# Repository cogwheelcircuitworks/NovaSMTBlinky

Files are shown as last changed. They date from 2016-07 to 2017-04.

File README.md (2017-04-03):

# NovaSMTBlinky

ATtiny-based, Surface-mount, 5x7 LED dot-matrix display board used in classes

More description over on https://hackaday.io/project/7788-nova-smt-blinky 

It has also been known to be for sale on Tindie: https://www.tindie.com/products/bcoggs/nova-smt-blinky--hackable-5x7-dot-matrix-/

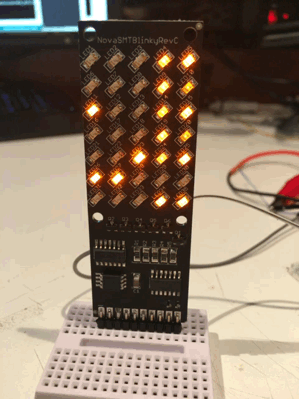
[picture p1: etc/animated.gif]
 

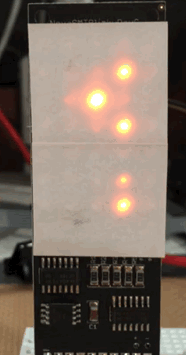
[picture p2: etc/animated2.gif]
 

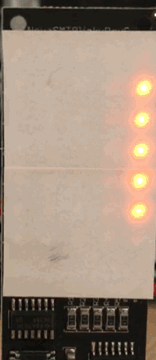
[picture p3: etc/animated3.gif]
 

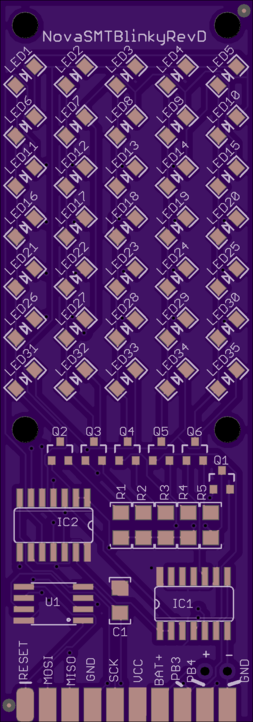
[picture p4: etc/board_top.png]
  

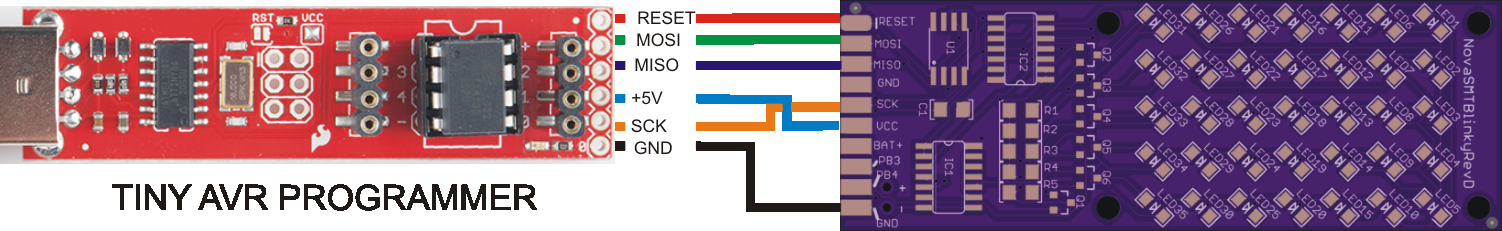
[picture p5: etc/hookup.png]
  

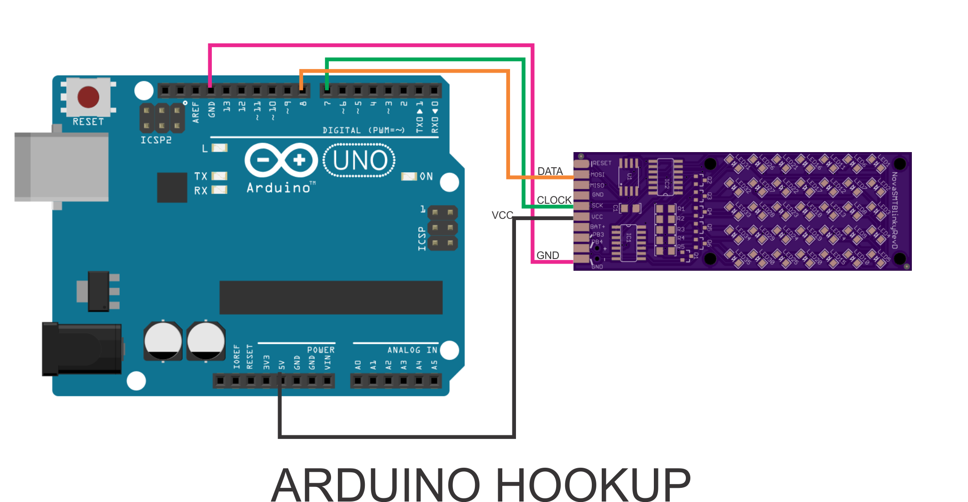
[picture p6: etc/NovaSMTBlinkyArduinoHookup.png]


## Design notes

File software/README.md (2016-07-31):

# SOFTWARE 

Arduino-compatible libraries

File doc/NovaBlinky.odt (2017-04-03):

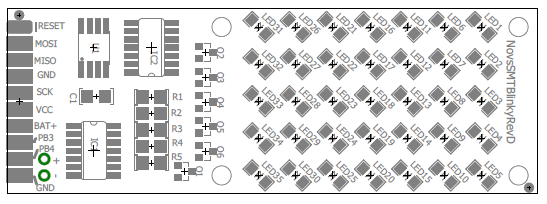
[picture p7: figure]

Nova SMT Blinky

Revision D
https://github.com/cogwheelcircuitworks/NovaSMTBlinky

Nova SMT Blinky is a 5x7 LED dot-matrix display board. It is used in kit form to teach surface-mount soldering classes. There is an assembled version as well.

Nova SMT Blinky uses an Microchip ATtiny 85 Processor. It can operate from 3 1.5V batteries or a 5 volt supply. It can be driven with either 5V or 3.3V sytems.

Nova SMT Blinky comes with firmware which allows it to be used as a smart display peripheral with a host system. There is a bar-graph mode. There are two dot-matrix character sets – 5x7 for one character, or 3x5 to display two characters side-side. There is also a raw mode where each individual led can be accessed.

Demo Mode

When supplied just power, Nova SMT Blinky will come up in 'demo' mode, showing off its various capabilities and special effects.

Driver Library

An Arduino-compatible library is available which can be used drive Nova SMT Blinky as a display peripheral

Source Code & Schematics

For people who would like to program Nova SMT Blinky directly, source code is included, which can be loaded into the Arduino IDE along with 3rd party support for AtTiny. New firmware can be flashed using a Tiny AVR Programmer available from SparkFun. Schematics and Eagle CAD files are also included.

# Using Blinky Stand-Alone

Nova SMT Blinky has a demo mode which is fun all by itself. Simply attach a 5V supply to the VCC pin along with a ground connection to GND. When it powers-up, it looks to see if the MOSI pin is being pulled down to ground. If it is pulled high or disconnected, demo mode will commence.

# Using Blinky as a Peripheral

There is an arduino-compatible driver located under software/libraries/NovaDotMatrixDriver/, in the github repository. Copy this to your Arduino IDE's libraries folder and restart the Arduino IDE. You will then be able to navigate to File -> Examples -> NovaDotMatrixDriver and load the example sketch.

At the top of the setup() function, note the pin assignments for clk_pin and data_pin. Attach clk_pin to to Nova SMT Blinky's SCK pin. Attach data_pin to the MOSI pin, along with 5V and GND. When the example sketch is started and Nova SMT Blinky reset, the sketch will run through various demonstrations.

The sketch uses 'bit-bang' mode, so you should be able to use Nova SMT Blinky with any digitial pins of any Arduino-compatible processor.

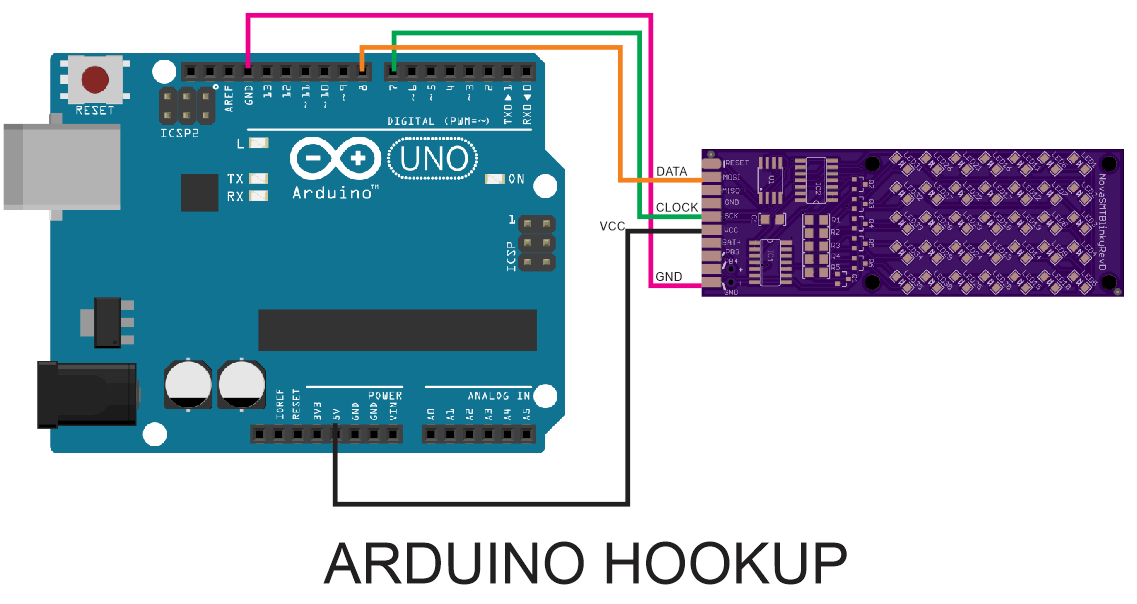
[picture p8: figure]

# Hacking on Blinky Software

Source code to Nova SMT Blinky is available under /software/libraries/NovaDotMatrix/ in the github repository. You will need a SparkFun TinyAVR Programmer. You will also need to install support for the Attiny into your Arduino IDE. Sparkfun has an excellent tutorial covering everything. Google /SparkFun Tiny AVR Programmer tutorial/ to access it.

Here is the hookup diagram:

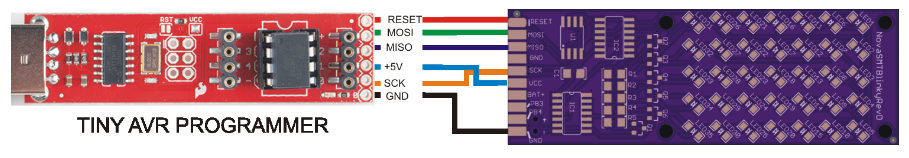
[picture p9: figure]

# Hardware Hacking

Schematics, board layout and Eagle CAD files are located in NovaSMTBlinky/hardware/RevD/ in the gitbhub repository.

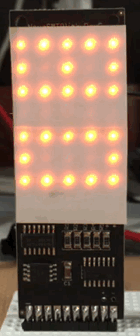
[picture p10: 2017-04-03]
etc/animated4.gif

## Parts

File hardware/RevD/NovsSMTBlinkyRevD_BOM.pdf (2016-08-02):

NovaSMTBlinky Rev D | BQTY | 5 ORD ord21feb
KEY QTY REFS MFR MFRPN | DESC
0.0 11 FID1 FID2 JP1 NoPart NoPart | NoPart 55 25
130.0 2 IC1 IC2 | NXP | SN74HC164D | IC 8BIT SHIFT REGISTER 14-SOIC | 10 50 | 50
1010.0 1 U1 | Atmega | ATTINY85-20SU | IC MCU 8BIT 8KB FLASH 8SOIC | 5 50
1011.5
6 | Fairchild | BSS84 | MOSFET P-CH 50V SOT23-3 | 30 10

1012.3

35 | generic | OrangeLed1206 | LED ORANGE 1206 | 175 25
1013.0 1 C1 | TDK | C3216X7R1C106M160AC | CAP CER 10UF 16V 20% X7R 1206 | 5 25
1018.0
5 | Vishay | CRCW1206470RJNEA | RES 470 ohm 1206 | 25 10
0.0 11 FID1 FID2 JP1 NoPart | NoPart | NoPart | 55 | 4

Q1 Q2 Q3 Q4
Q5 Q6
LED1 LED2
LED3 LED4
LED5 LED6
LED7 LED8
LED9 LED10
LED11 LED12
LED13 LED14
LED15 LED16
LED17 LED18
LED19 LED20
LED21 LED22
LED23 LED24
LED25 LED26
LED27 LED28
LED29 LED30
LED31 LED32
LED33 LED34
LED35

R1 R2 R3 R4
R5

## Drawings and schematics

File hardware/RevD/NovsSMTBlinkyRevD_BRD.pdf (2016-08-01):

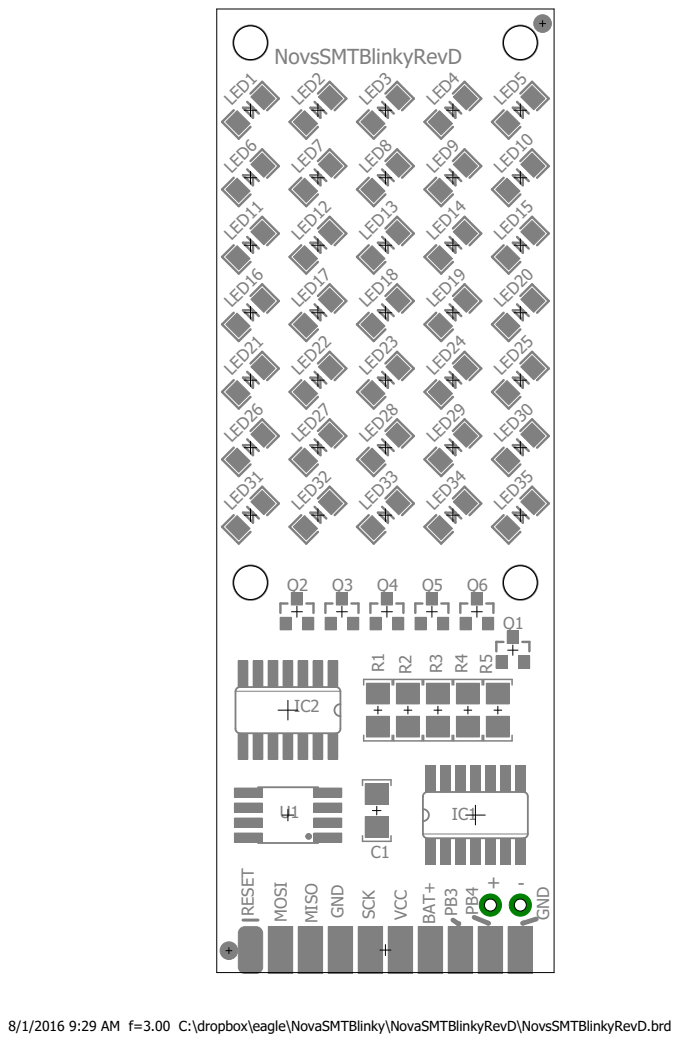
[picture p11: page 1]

8/1/2016 9:29 AM f=3.00 C:\dropbox\eagle\NovaSMTBlinky\NovaSMTBlinkyRevD\NovsSMTBlinkyRevD.brd

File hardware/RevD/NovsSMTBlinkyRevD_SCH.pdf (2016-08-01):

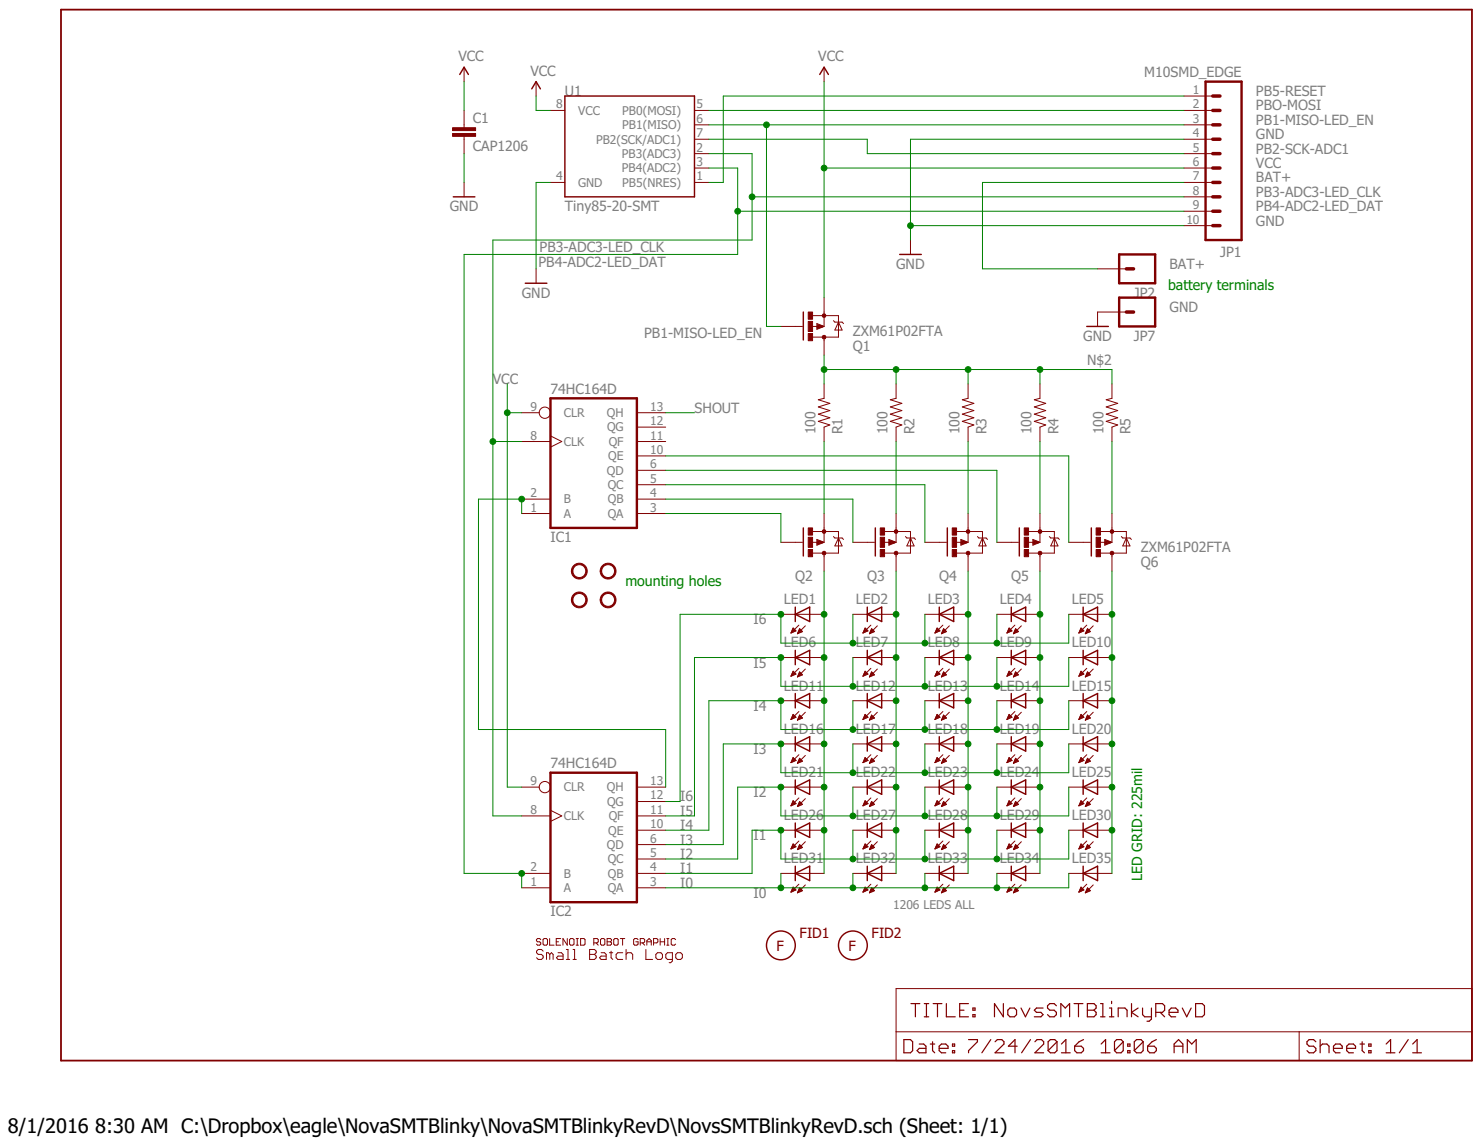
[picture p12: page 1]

5 QD
4 QC

8/1/2016 8:30 AM C:\Dropbox\eagle\NovaSMTBlinky\NovaSMTBlinkyRevD\NovsSMTBlinkyRevD.sch (Sheet: 1/1)

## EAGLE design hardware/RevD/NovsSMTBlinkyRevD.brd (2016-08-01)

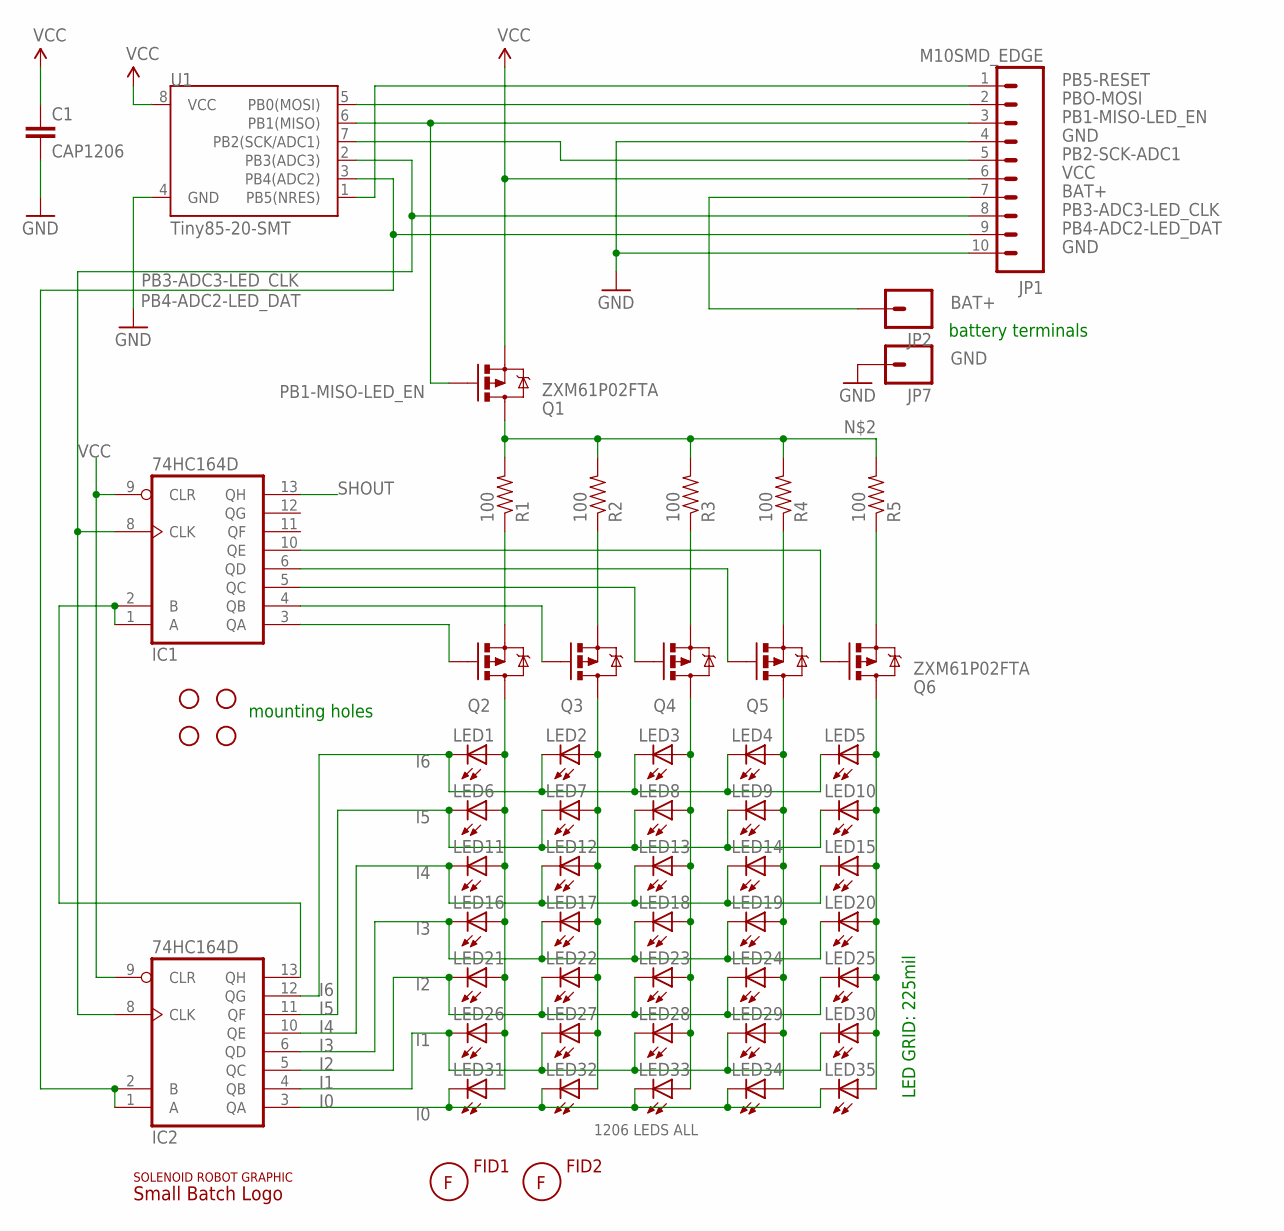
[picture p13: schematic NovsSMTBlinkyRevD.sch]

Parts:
C1: CAP1206; 1206
FID1, FID2: FIDUCIAL; FID05MM
IC1, IC2: 74HC164D; SO14
JP1: M10SMD_EDGE; 1X10_SMD_EDGE
JP2, JP7: M01NOSILK-KIT; 1X01NS-KIT
JP3, JP4, JP5, JP6: MTGHOLE110MIL; HOLE112
LED1, LED2, LED3, LED4, LED5, LED6, LED7, LED8, LED9, LED10, LED11, LED12, LED13, LED14, LED15, LED16, LED17, LED18, LED19, LED20, LED21, LED22, LED23, LED24, LED25, LED26, LED27, LED28, LED29, LED30, LED31, LED32, LED33, LED34, LED35: LED1206; LED-1206
Q1, Q6: ZXM61P02FTA; SOT23-3
Q2, Q3, Q4, Q5: MOSFET-PCHANNELSMD; SOT23-3
R1, R2, R3, R4, R5: 100; 1206
U1: Tiny85-20-SMT; SO08-EIAJ
U$1: SOLENOID_ROBOT; SOLENOID_ROBT_450MIL
U$4: SMALLBATCH_LOGO750W; SMALLBATCH_750W

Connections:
BAT+: JP1.7, JP2.1
GND: C1.2, IC1.7 (GND), IC2.7 (GND), JP1.4, JP1.10, JP7.1, U1.4 (GND)
I0: IC2.3 (QA), LED31.C, LED32.C, LED33.C, LED34.C, LED35.C
I1: IC2.4 (QB), LED26.C, LED27.C, LED28.C, LED29.C, LED30.C
I2: IC2.5 (QC), LED21.C, LED22.C, LED23.C, LED24.C, LED25.C
I3: IC2.6 (QD), LED16.C, LED17.C, LED18.C, LED19.C, LED20.C
I4: IC2.10 (QE), LED11.C, LED12.C, LED13.C, LED14.C, LED15.C
I5: IC2.11 (QF), LED6.C, LED7.C, LED8.C, LED9.C, LED10.C
I6: IC2.12 (QG), LED1.C, LED2.C, LED3.C, LED4.C, LED5.C
unnamed: IC1.1 (A), IC1.2 (B), IC2.13 (QH)
unnamed: Q1.3 (D), R1.2, R2.2, R3.2, R4.2, R5.2
unnamed: LED1.A, LED6.A, LED11.A, LED16.A, LED21.A, LED26.A, LED31.A, Q2.3 (D)
unnamed: LED2.A, LED7.A, LED12.A, LED17.A, LED22.A, LED27.A, LED32.A, Q3.3 (D)
unnamed: LED4.A, LED9.A, LED14.A, LED19.A, LED24.A, LED29.A, LED34.A, Q5.3 (D)
unnamed: LED5.A, LED10.A, LED15.A, LED20.A, LED25.A, LED30.A, LED35.A, Q6.3 (D)
unnamed: LED3.A, LED8.A, LED13.A, LED18.A, LED23.A, LED28.A, LED33.A, Q4.3 (D)
unnamed: Q2.2 (S), R1.1
unnamed: Q3.2 (S), R2.1
unnamed: Q4.2 (S), R3.1
unnamed: Q5.2 (S), R4.1
unnamed: Q6.2 (S), R5.1
unnamed: IC1.3 (QA), Q2.1 (G)
unnamed: IC1.4 (QB), Q3.1 (G)
unnamed: IC1.5 (QC), Q4.1 (G)
unnamed: IC1.6 (QD), Q5.1 (G)
unnamed: IC1.10 (QE), Q6.1 (G)
PB1-MISO-LED_EN: JP1.3, Q1.1 (G), U1.6 (PB1(MISO))
PB2-SCK-ADC1: JP1.5, U1.7 (PB2(SCK/ADC1))
PB3-ADC3-LED_CLK: IC1.8 (CLK), IC2.8 (CLK), JP1.8, U1.2 (PB3(ADC3))
PB4-ADC2-LED_DAT: IC2.1 (A), IC2.2 (B), JP1.9, U1.3 (PB4(ADC2))
PB5-RESET: JP1.1, U1.1 (PB5(NRES))
PBO-MOSI: JP1.2, U1.5 (PB0(MOSI))
SHOUT: IC1.13 (QH)
VCC: C1.1, IC1.9 (CLR), IC1.14 (VCC), IC2.9 (CLR), IC2.14 (VCC), JP1.6, Q1.2 (S), U1.8 (VCC)

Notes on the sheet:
1206 LEDS ALL
mounting holes
LED GRID: 225mil
battery terminals

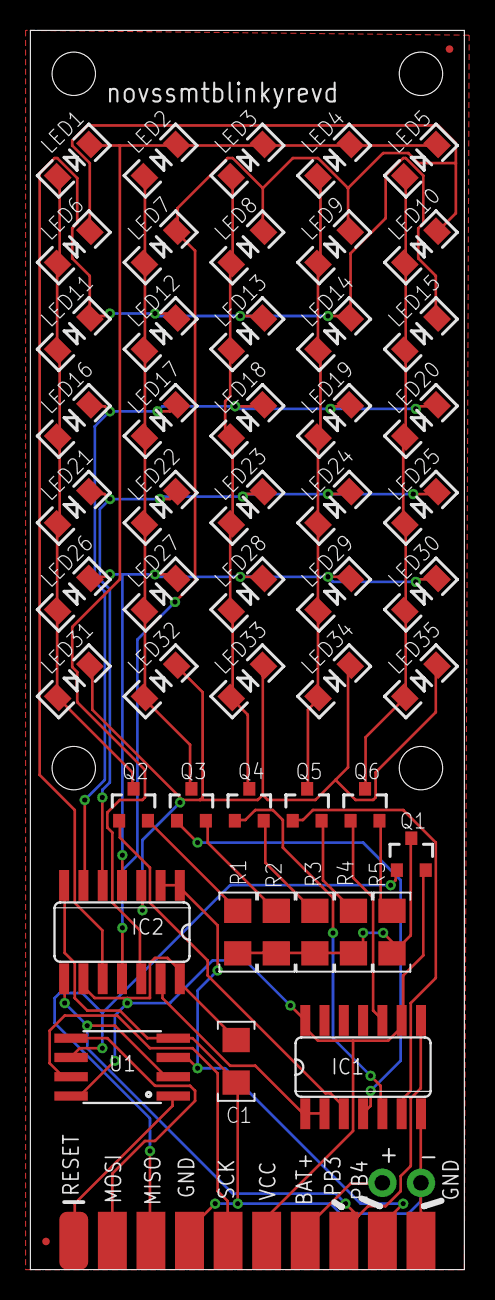
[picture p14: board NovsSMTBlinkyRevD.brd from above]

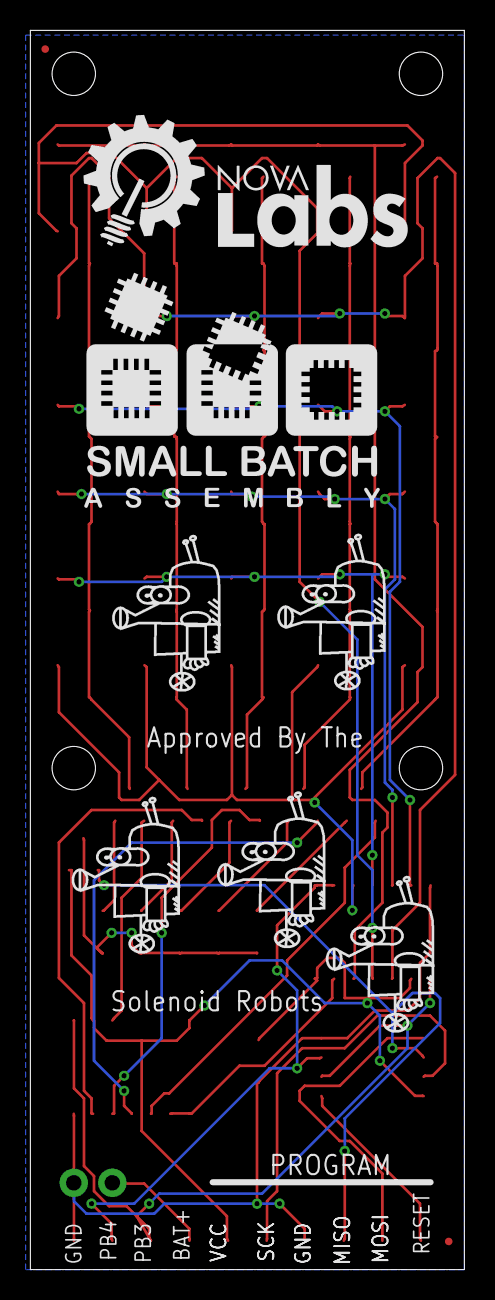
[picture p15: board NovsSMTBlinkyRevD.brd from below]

Board: 2 copper layers, 28.6 x 81.6 mm, 66 parts (7 on the bottom side), 33 nets.

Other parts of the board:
U$2: NOVA-LABS-LOGO-FULL-SMALL
U$3, U$5, U$6, U$7: SOLENOID_ROBOT; SOLENOID_ROBT_450MIL

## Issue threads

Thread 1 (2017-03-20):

Missing bottom silkscreen

JarrettR, 2017-03-20:
Seems a waste of a canvas to not include a logo and website for your makerspace :)

cogwheelcircuitworks, 2017-03-21:
Good point. Next batch.

Closed 2017-03-21.

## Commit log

2015-09-22 new file: hardware/RevX/NovaSMTPracticeErrata.doc new file: hardware/RevX/NovaSMTPracticeVX-BOM.pdf new file: hardware/RevX/NovaSMTPracticeVX-sch.pdf new file: hardware/RevX/NovaSMTPracticeVX.brd new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
    [NovaSMTPracticeVX.brd, NovaSMTPracticeVX.sch]
2015-09-22 new file: hardware/RevX/NovaSMTPracticeRevA-brd.pdf new file: hardware/RevX/NovaSMTPracticeVX-Fab/NovaSMTPracticeVX.boardoutline.ger new file: hardware/RevX/NovaSMTPracticeVX-Fab/NovaSMTPracticeVX.bo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
    [NovaSMTPracticeVX.drills.xln]
2015-09-22 new file: software/hardware/attiny/avr/boards.txt new file: software/hardware/attiny/avr/platform.txt new file: software/hardware/attiny/avr/variants/tiny14/pins_arduino.h new file: software/hardware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
2016-07-31 Major revsion
    deleted: software/hardware/attiny/avr/boards.txt
    deleted: software/hardware/attiny/avr/platform.txt
    deleted: software/hardware/attiny/avr/variants/tiny14/pins_arduino.h
    deleted: software/hardware/attiny/avr/variants/tiny8/pins_arduino.h
    deleted: software/libraries/ATtinyTimer/ATtinyTimer.cpp
    deleted: software/libraries/ATtinyTimer/ATtinyTimer.h
    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
2016-08-01 new file: etc/board_top.png
2016-08-01 modified: etc/board_top.png
2016-08-01 new file: RevD/NovaSMTBlinkyRevD.xls renamed: RevX/NovaSMTPracticeVX.brd -> RevD/NovsSMTBlinkyRevD.brd renamed: RevX/NovaSMTPracticeVX.sch -> RevD/NovsSMTBlinkyRevD.sch new file: RevD/NovsSMTBlinkyRe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
    [NovaSMTBlinkyRevD.xls, NovaSMTPracticeVX.brd, NovaSMTPracticeVX.sch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]
2016-08-02 deleted: NovaSMTBlinkyRevD.xls deleted: NovsSMTBlinkyRevD_SBA_BOM.csv
    [NovaSMTBlinkyRevD.xls, NovsSMTBlinkyRevD_SBA_BOM.csv]
2017-04-03 Added Arduino Hookup d'gram to doc/NovaBlinky.odt, doc/NovaBlinky.pdf

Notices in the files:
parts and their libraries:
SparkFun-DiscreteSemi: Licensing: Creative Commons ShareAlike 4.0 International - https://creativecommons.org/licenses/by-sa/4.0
